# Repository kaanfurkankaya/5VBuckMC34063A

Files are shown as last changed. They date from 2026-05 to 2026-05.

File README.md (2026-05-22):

# MC34063A ile 5V Düşürücü Regülatör

Bu proje, **MC34063AP** anahtarlamalı regülatör entegresi ile hazırlanmış bir **5V DC buck regülatör** KiCad tasarımıdır. Kart; DC girişten sabit **5V DC çıkış** üretmek için tasarlanmıştır ve through-hole parçalarla kolay montaj hedeflenmiştir.

> Not: Kart üzerindeki eski notlarda giriş 6.5-9V gibi düşünülmüş olabilir. MC34063A datasheet'inde entegre giriş aralığı **3V-40V** olarak verilir ve 5V/500mA düşürücü örneği **15V-25V giriş** ile gösterilir. Bu yüzden tasarım 9V ile sınırlı değildir; ancak üst giriş sınırı kullanılan kondansatör, diyot, bobin ve ısınma koşullarına göre doğrulanmalıdır.

## Görseller

### Şematik

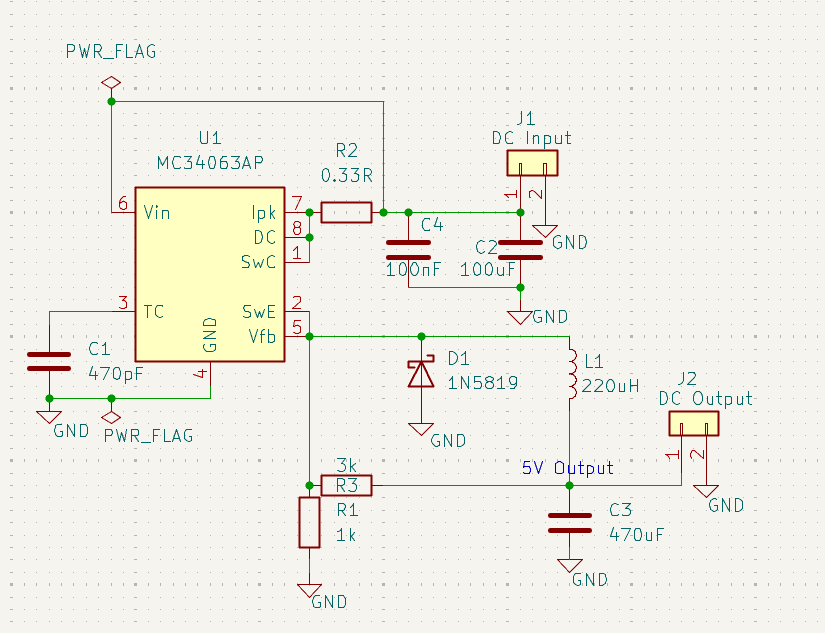
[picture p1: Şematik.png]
Şematik


### PCB Görünümü

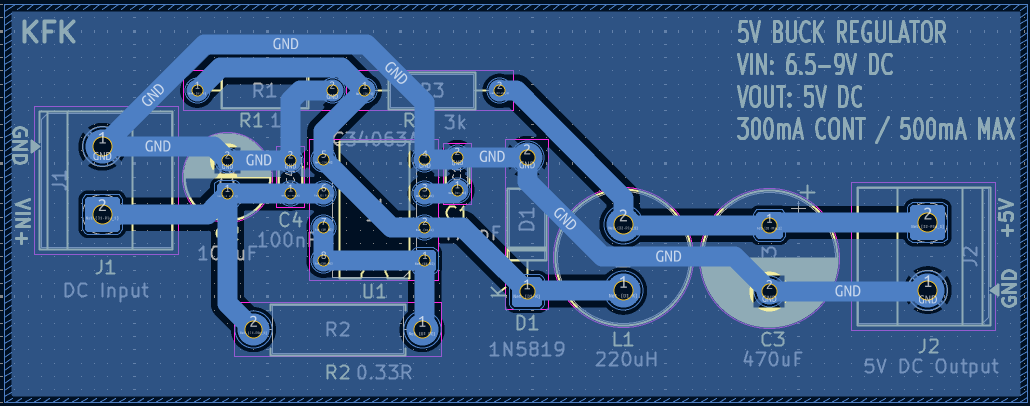
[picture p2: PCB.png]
PCB görünümü


### 3D Kart Görünümü

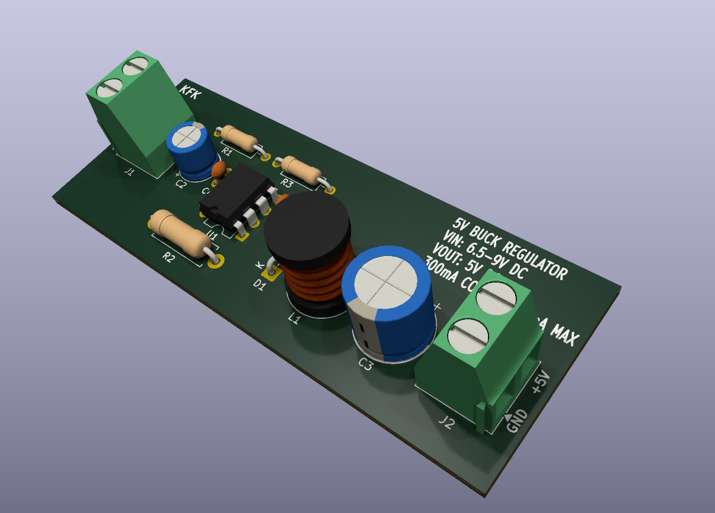
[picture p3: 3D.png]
3D kart görünümü


## Teknik Özellikler

- **Giriş:** 6.5V DC ve üzeri
- **Çıkış:** 5V DC
- **Hedef akım:** 300mA sürekli, 500mA maksimum
- **Regülatör entegresi:** MC34063AP, DIP-8
- **Topoloji:** Düşürücü / buck converter
- **PCB boyutu:** Yaklaşık 77mm x 30mm
- **Tasarım aracı:** KiCad 9.0

## Devre Notları

Datasheet'e göre MC34063A; yükseltici, düşürücü ve tersleyici regülatör uygulamaları için gerekli osilatör, referans, karşılaştırıcı, akım sınırlama ve anahtarlama transistörünü içinde barındırır.

Bu kartta çıkış gerilimi geri besleme dirençleriyle ayarlanır:

```text
Vout = 1.25V x (1 + R3 / R1)
R1 = 1k
R3 = 3k
Vout ~= 5V
```

Akım sınırlama direnci `R2 = 0.33R` seçilmiştir. Datasheet formülüne göre yaklaşık tepe anahtar akımı:

```text
Ipk ~= 0.3V / Rsc
Ipk ~= 0.3V / 0.33R ~= 0.9A
```

Bu değer çıkış akımıyla aynı şey değildir; bobin doyma akımı, diyot akımı, kart ısısı ve giriş gerilimi mutlaka dikkate alınmalıdır.

## Ana Parçalar

| Referans | Değer / Parça | Açıklama |
|---|---:|---|
| U1 | MC34063AP | Anahtarlamalı regülatör entegresi |
| D1 | 1N5819 | Schottky diyot |
| L1 | 220uH | Buck bobini |
| R1 | 1k | Geri besleme alt direnci |
| R3 | 3k | Geri besleme üst direnci |
| R2 | 0.33R | Akım sınırlama direnci |
| C1 | 470pF | Zamanlama kondansatörü |
| C2 | 100uF | Giriş kondansatörü |
| C3 | 470uF | Çıkış kondansatörü |
| C4 | 100nF | Bypass kondansatörü |
| J1 | DC Input | Giriş klemensi |
| J2 | DC Output | 5V çıkış klemensi |

## Dosyalar

- `5VBuckMC34063A.kicad_sch`: Devre şeması
- `5VBuckMC34063A.kicad_pcb`: PCB yerleşimi
- `5VBuckMC34063A.kicad_pro`: KiCad proje dosyası
- `5VBuckMC34063A-ÖnYüz.pdf`: Ön yüz baskı çıktısı
- `5VBuckMC34063A-Bakır.pdf`: Bakır yüz baskı çıktısı
- `5VBuckMC34063A-backups/`: KiCad otomatik yedekleri

## Kullanım

1. `J1` klemensinden DC giriş uygulayın.
2. Polariteye dikkat edin: `VIN+` ve `GND` ters bağlanmamalıdır.
3. `J2` klemensinden 5V çıkış alın.
4. İlk testte akım sınırlı güç kaynağı kullanın.
5. 9V üzeri girişlerde parça voltaj değerlerini ve regülatör sıcaklığını kontrol edin.

## Datasheet

- [TI MC34063A / MC33063A Datasheet]([https://www.onsemi.com/download/data-sheet/pdf/mc34063a-d.pdf](https://www.ti.com/lit/ds/symlink/mc34063a.pdf))

## Uyarı

Bu kart hobi ve prototip amaçlı bir tasarımdır. Yüksek giriş gerilimlerinde, yüksek yük akımlarında veya uzun süreli çalışmada sıcaklık, ripple ve parça limitleri ölçülerek doğrulanmalıdır.

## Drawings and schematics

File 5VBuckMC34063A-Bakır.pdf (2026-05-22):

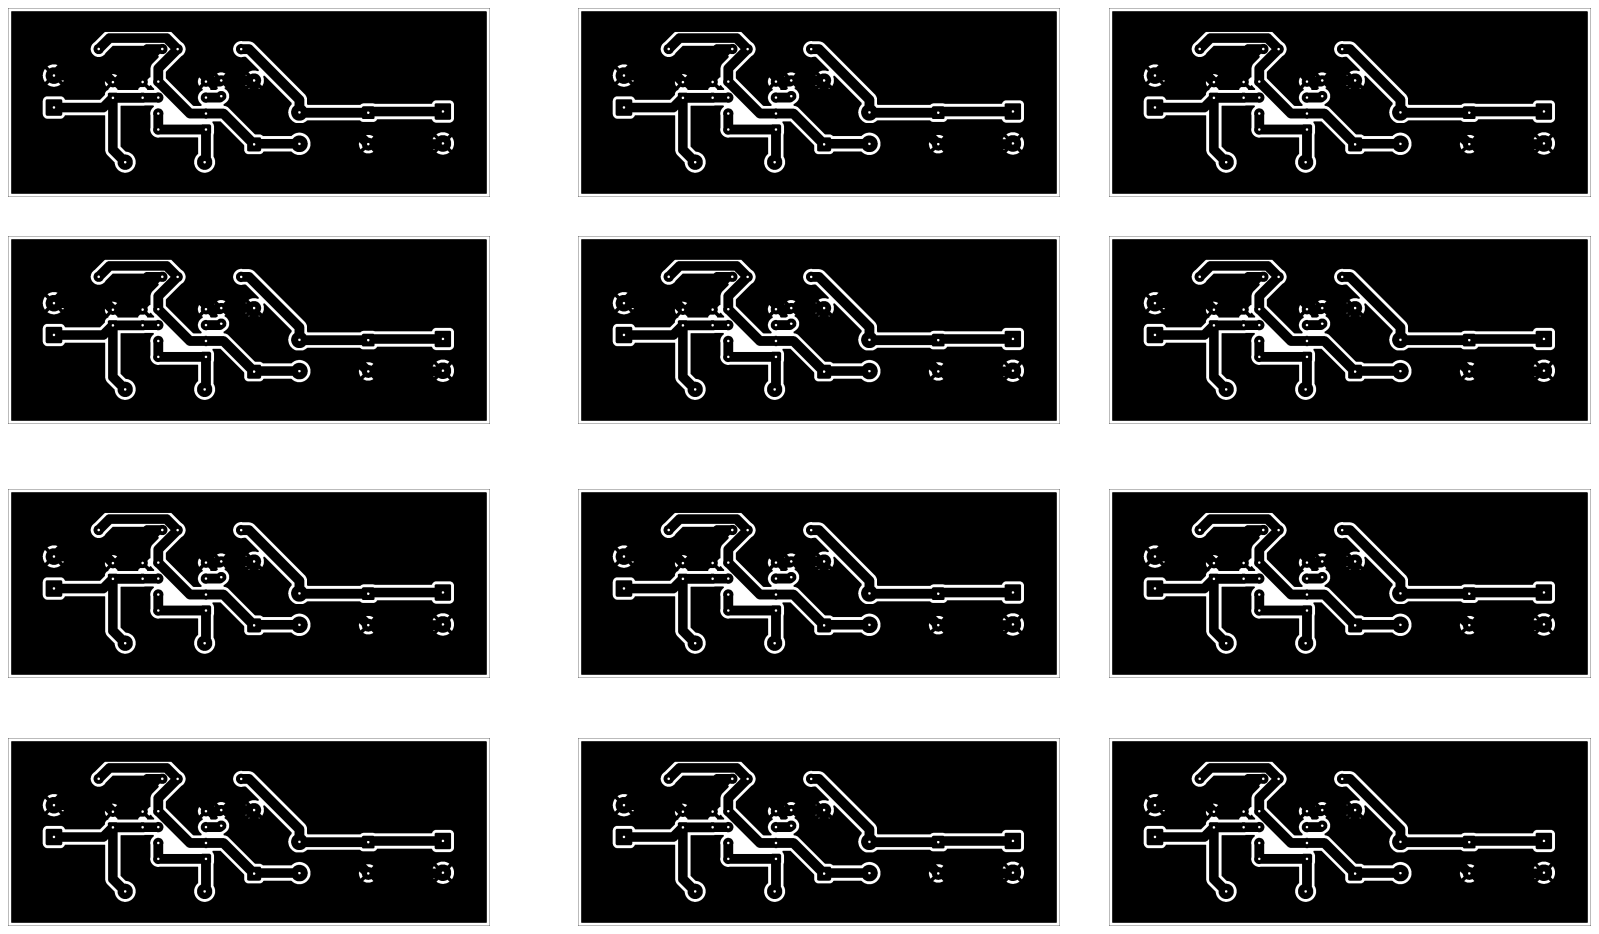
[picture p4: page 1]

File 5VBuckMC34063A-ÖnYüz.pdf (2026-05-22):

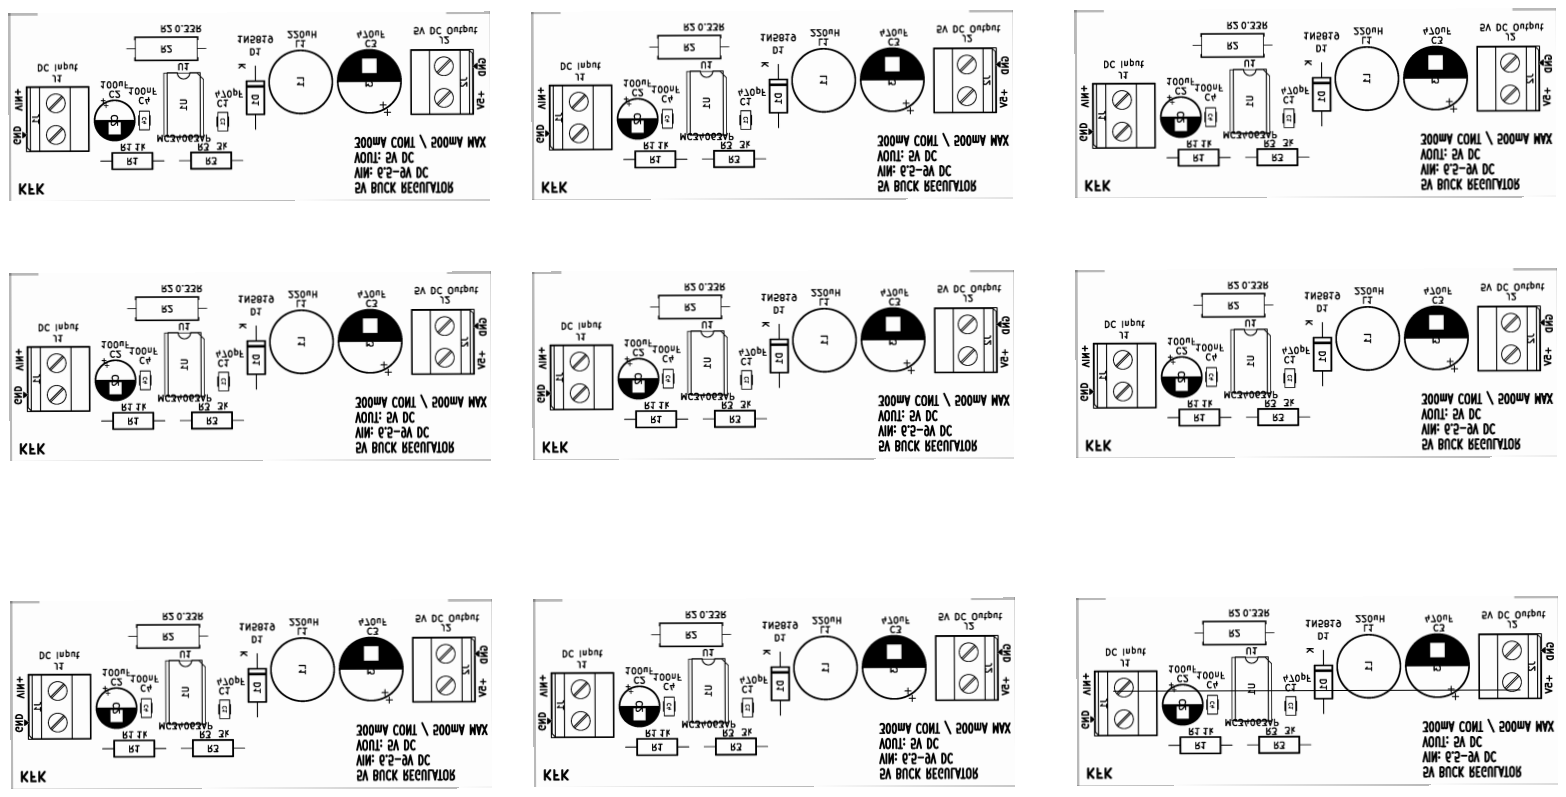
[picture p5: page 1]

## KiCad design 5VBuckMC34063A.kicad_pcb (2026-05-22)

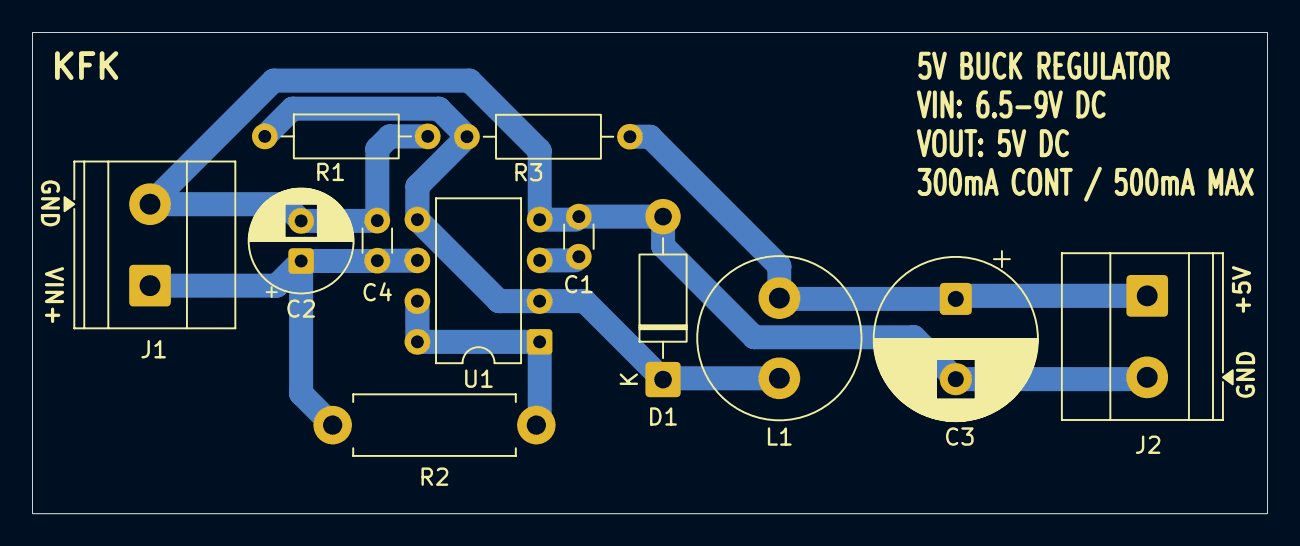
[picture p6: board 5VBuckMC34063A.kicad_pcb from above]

Board: 2 copper layers, 77.0 x 30.0 mm, 12 parts (0 on the bottom side), 6 nets.

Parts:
C1: 470pF; C_Disc_D3.0mm_W1.6mm_P2.50mm
C2: 100uF; CP_Radial_D6.3mm_P2.50mm
C3: 470uF; CP_Radial_D10.0mm_P5.00mm
C4: 100nF; C_Disc_D3.0mm_W1.6mm_P2.50mm
D1: 1N5819; D_DO-41_SOD81_P10.16mm_Horizontal
J1: DC Input; TerminalBlock_Phoenix_MKDS-1,5-2-5.08_1x02_P5.08mm_Horizont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
J2: 5V DC Output; TerminalBlock_Phoenix_MKDS-1,5-2-5.08_1x02_P5.08mm_Horizont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
L1: 220uH; L_Radial_D10.0mm_P5.00mm_Fastron_07M
R1: 1k; R_Axial_DIN0207_L6.3mm_D2.5mm_P10.16mm_Horizontal
R2: 0.33R; R_Axial_DIN0411_L9.9mm_D3.6mm_P12.70mm_Horizontal
R3: 3k; R_Axial_DIN0207_L6.3mm_D2.5mm_P10.16mm_Horizontal
U1: MC34063AP; DIP-8_W7.62mm

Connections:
GND: C1.2, C2.2, C3.2, C4.2, D1.2 (A), J1.1, J2.1, R1.2, U1.4 (GND)
unnamed: D1.1 (K), L1.1, R1.1, R3.1, U1.2 (SwE), U1.5 (Vfb)
unnamed: C2.1, C4.1, J1.2, R2.2, U1.6 (Vin)
unnamed: C3.1, J2.2, L1.2, R3.2
unnamed: R2.1, U1.1 (SwC), U1.7 (Ipk), U1.8 (DC)
unnamed: C1.1, U1.3 (TC)
